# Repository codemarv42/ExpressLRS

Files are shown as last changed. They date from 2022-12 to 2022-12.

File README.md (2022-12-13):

# ExpressLRS

ExpressLRS is an open source project that enables the connection between drone and remote control in an efficient way. To support the project itself a little bit, I have developed other hardware alternatives, which are of course also open source. To support the project visit: https://github.com/ExpressLRS/ExpressLRS

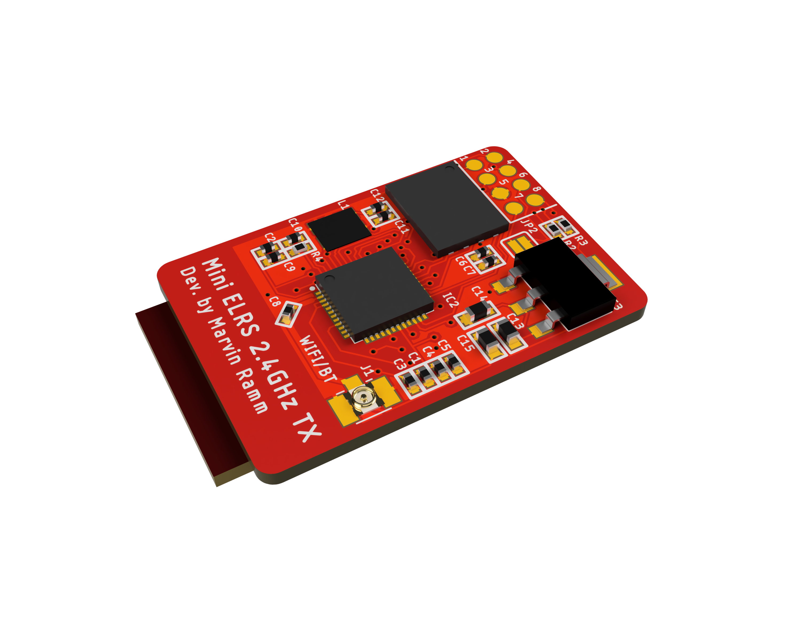
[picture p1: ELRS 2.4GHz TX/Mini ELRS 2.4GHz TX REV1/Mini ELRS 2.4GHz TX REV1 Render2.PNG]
ELRS_Render


Parameter for TX Mini REV1:

- Layer: 2
- Thickness: 1,2mm
- Minimum Copper Trace Width: 0.15mm

## Improvements

> - [ ] Pin 0 (Boot) to GND Pad for initial upload of the program

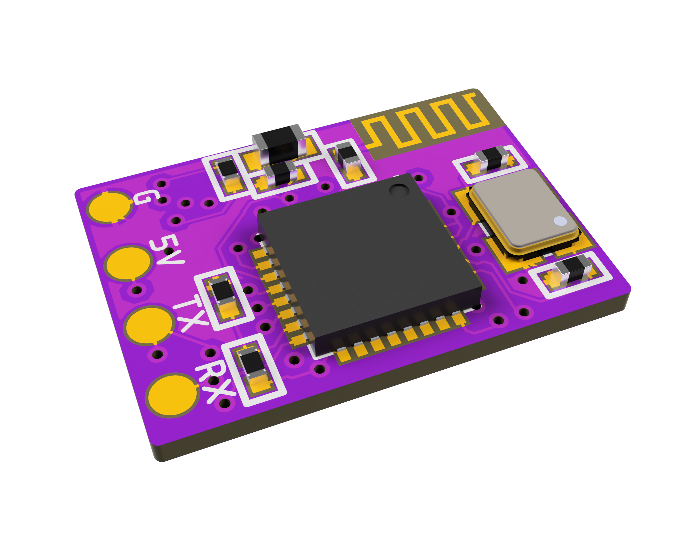
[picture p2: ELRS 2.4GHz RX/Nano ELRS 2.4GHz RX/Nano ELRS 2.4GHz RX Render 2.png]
ELRS_Render


Parameter for RX Nano REV1:

- Layer: 4
- Thickness: 1,2mm / 1mm
- Minimum Copper Trace Width: 0.09mm

ELRS_Render

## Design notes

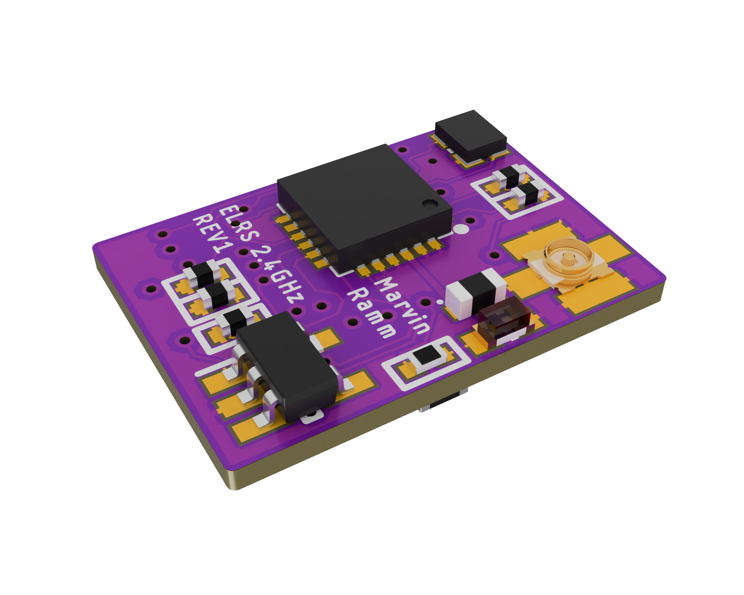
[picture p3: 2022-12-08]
ELRS 2.4GHz RX/Nano ELRS 2.4GHz RX/Nano ELRS 2.4GHz RX Render 1.png

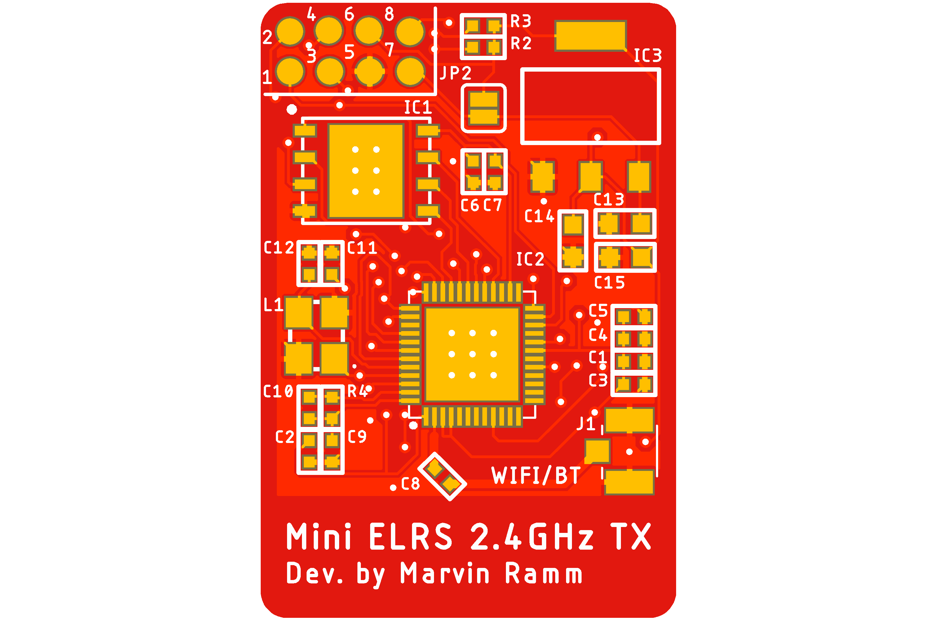
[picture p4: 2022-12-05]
ELRS 2.4GHz TX/Mini ELRS 2.4GHz TX REV1/Mini ELRS 2.4GHz TX_1.png

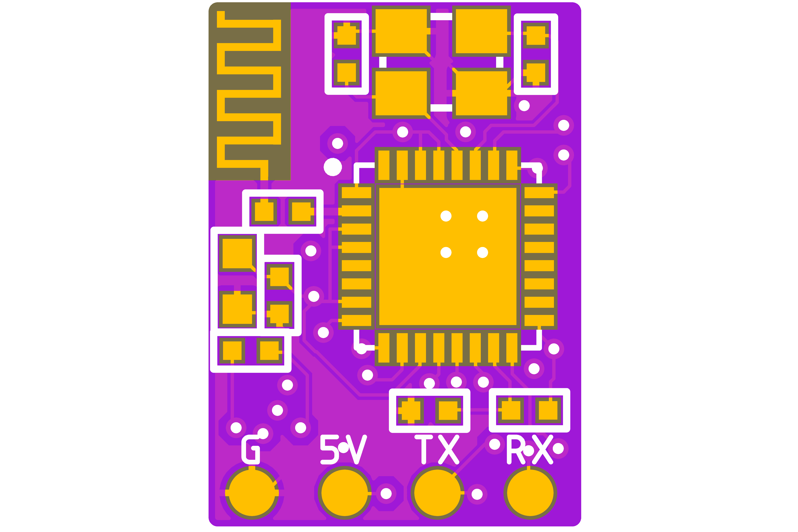
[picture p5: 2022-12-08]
ELRS 2.4GHz RX/Nano ELRS 2.4GHz RX/Nano ELRS 2.4GHz RX_3.png

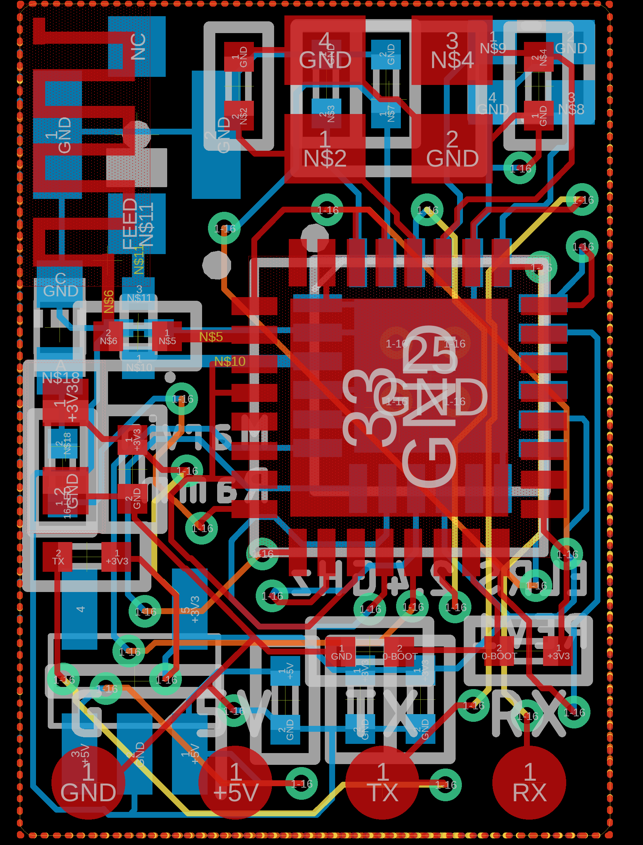
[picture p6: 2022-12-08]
ELRS 2.4GHz RX/Nano ELRS 2.4GHz RX/Nano ELRS 2.4GHz RX_1.png

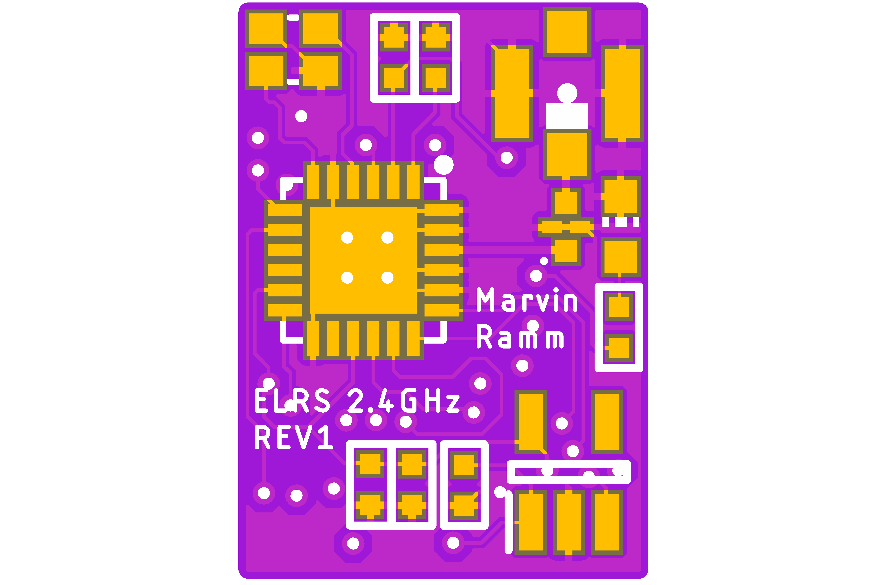
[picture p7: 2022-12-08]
ELRS 2.4GHz RX/Nano ELRS 2.4GHz RX/Nano ELRS 2.4GHz RX_2.png

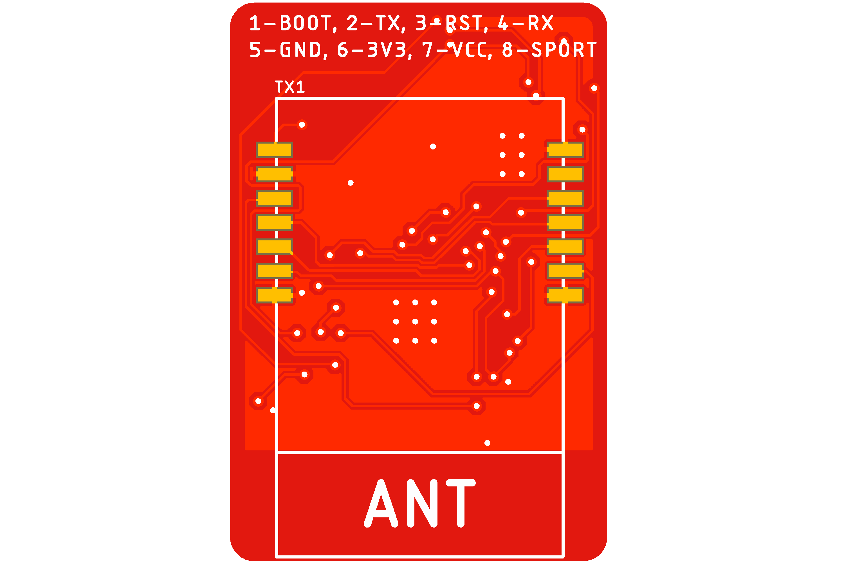
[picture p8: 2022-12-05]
ELRS 2.4GHz TX/Mini ELRS 2.4GHz TX REV1/Mini ELRS 2.4GHz TX_2.png

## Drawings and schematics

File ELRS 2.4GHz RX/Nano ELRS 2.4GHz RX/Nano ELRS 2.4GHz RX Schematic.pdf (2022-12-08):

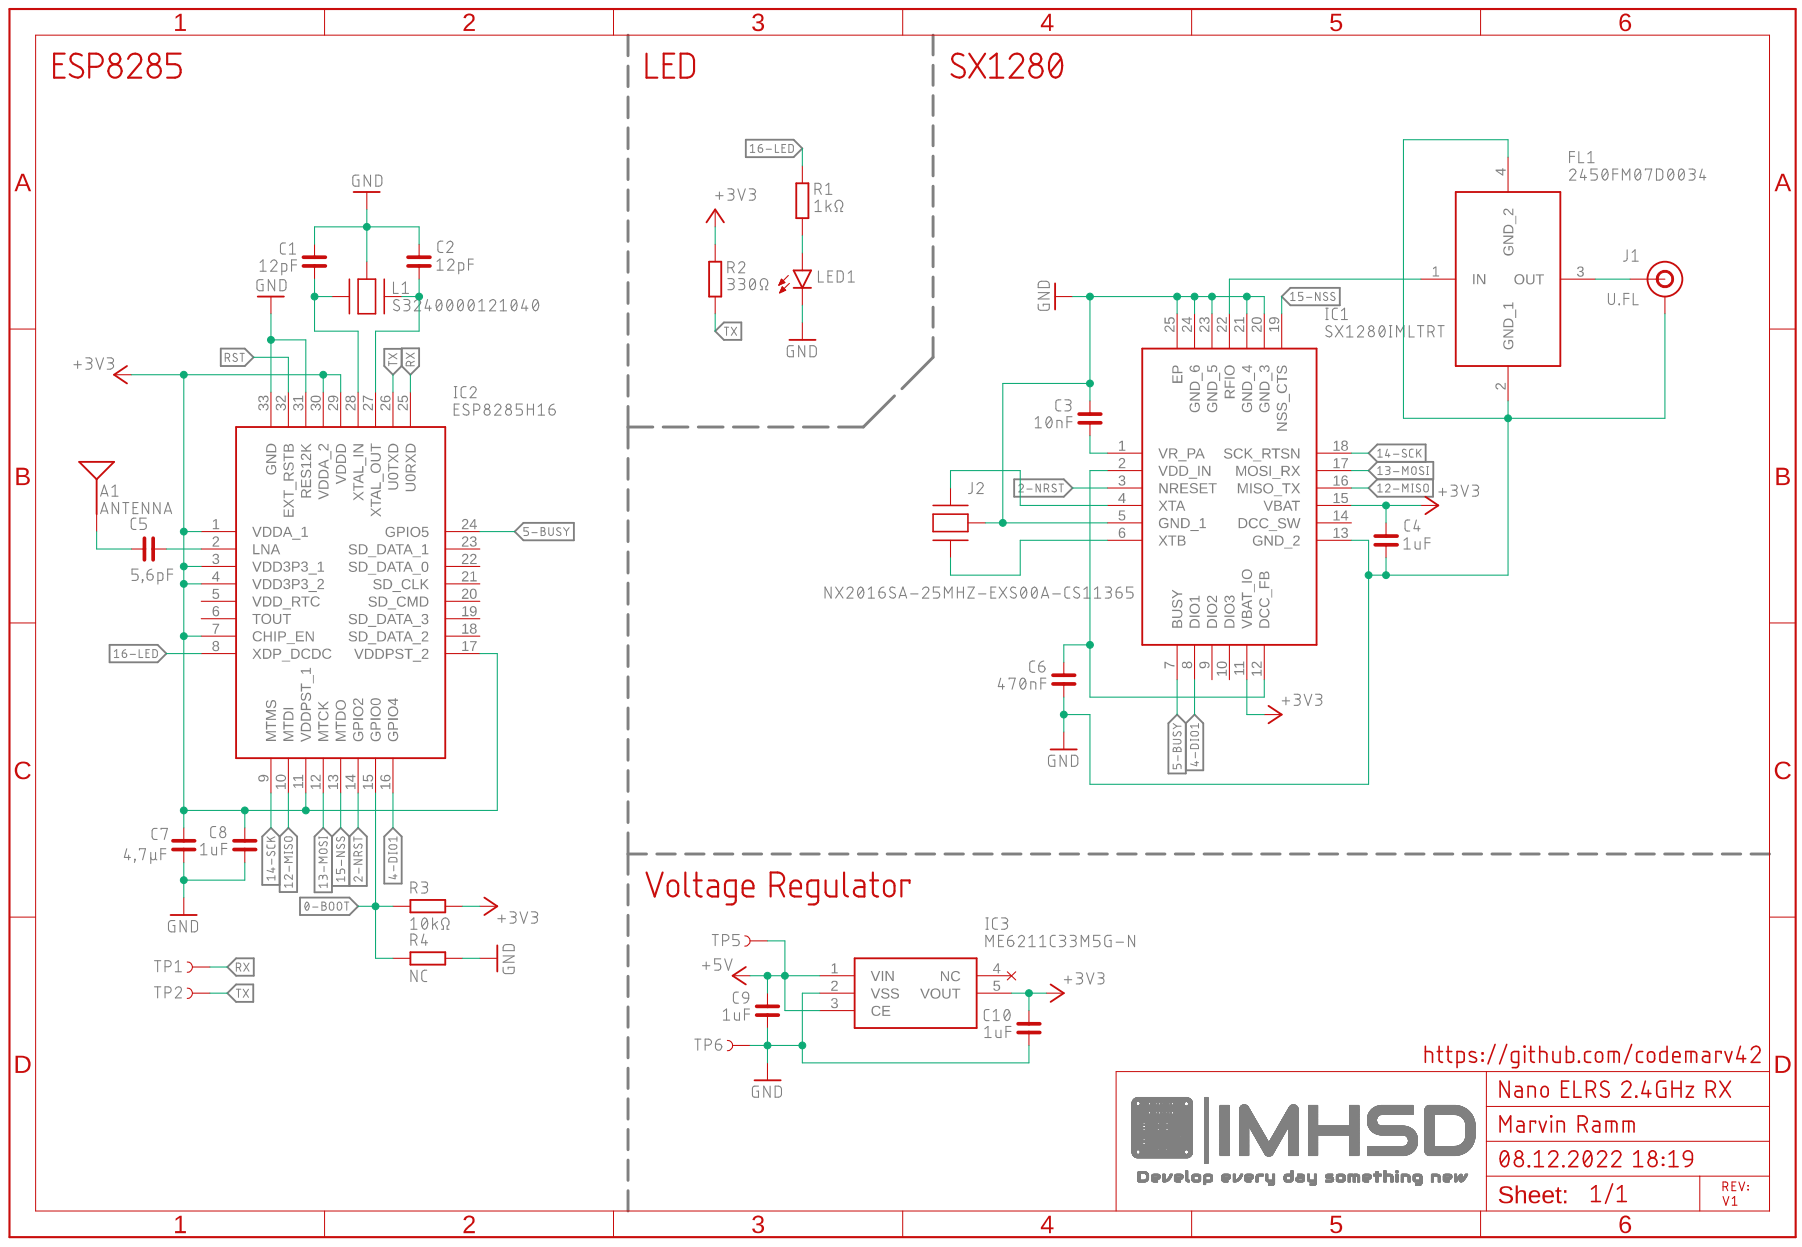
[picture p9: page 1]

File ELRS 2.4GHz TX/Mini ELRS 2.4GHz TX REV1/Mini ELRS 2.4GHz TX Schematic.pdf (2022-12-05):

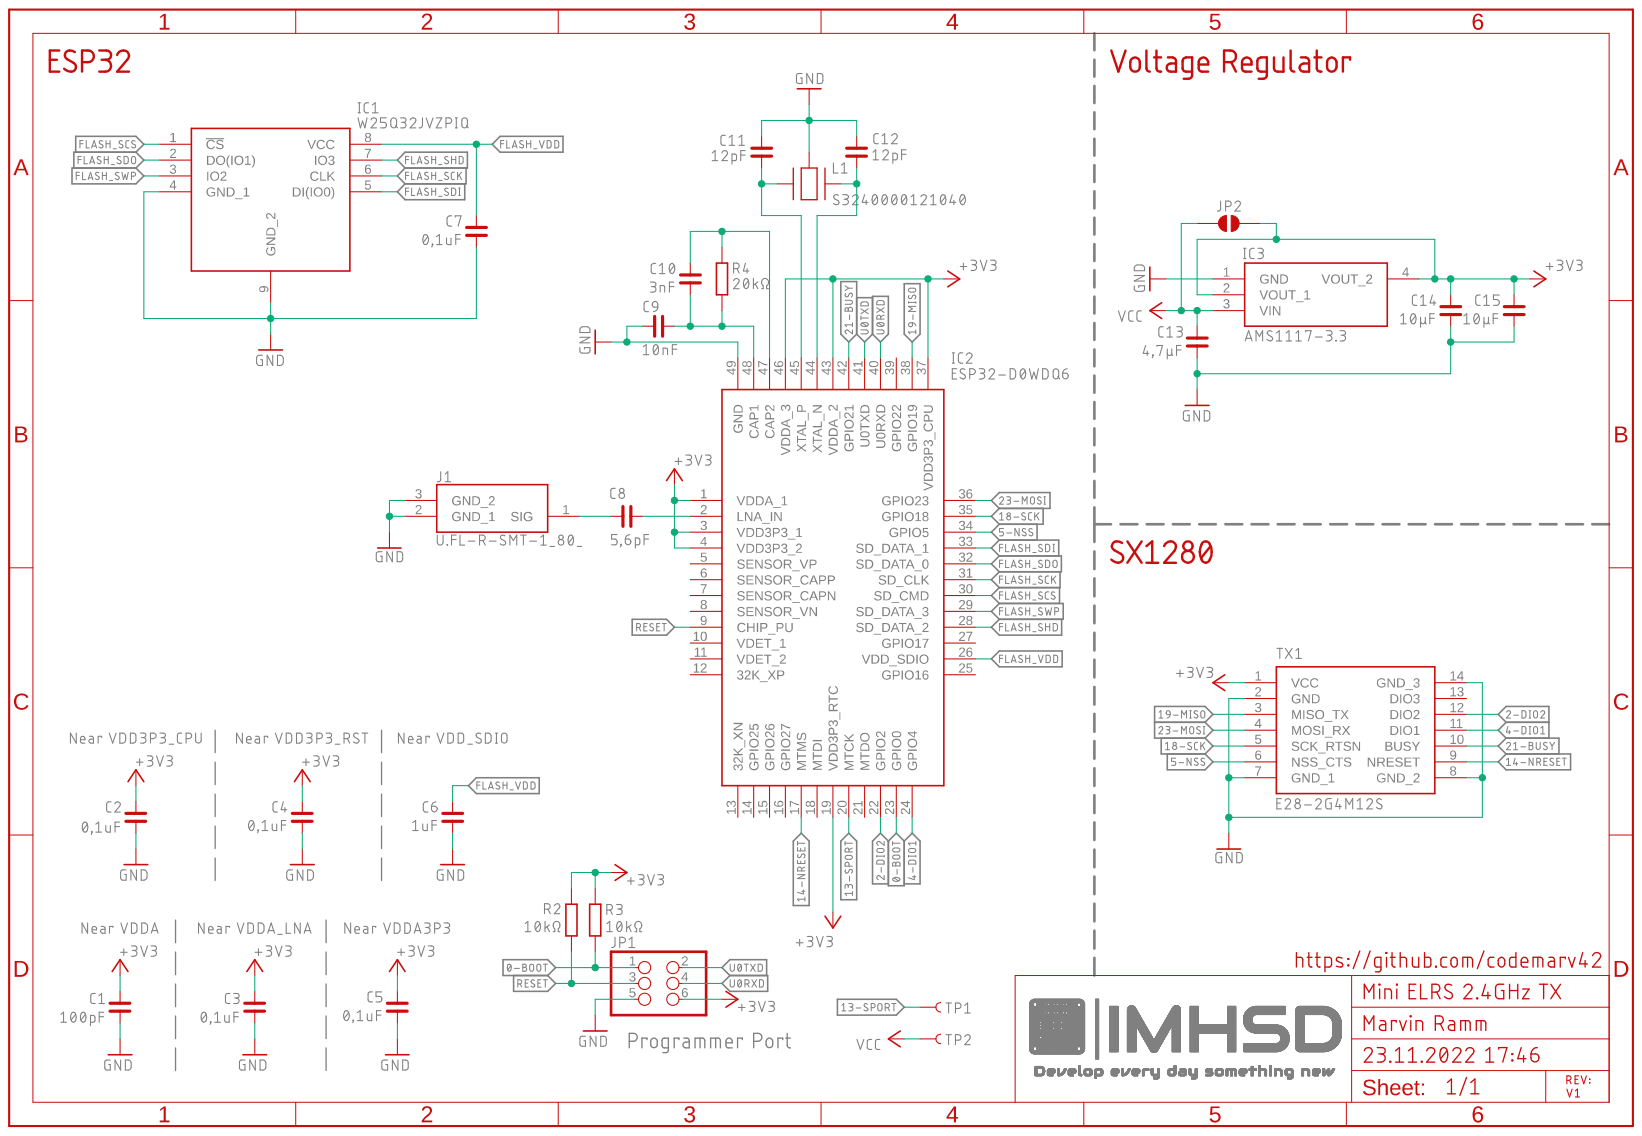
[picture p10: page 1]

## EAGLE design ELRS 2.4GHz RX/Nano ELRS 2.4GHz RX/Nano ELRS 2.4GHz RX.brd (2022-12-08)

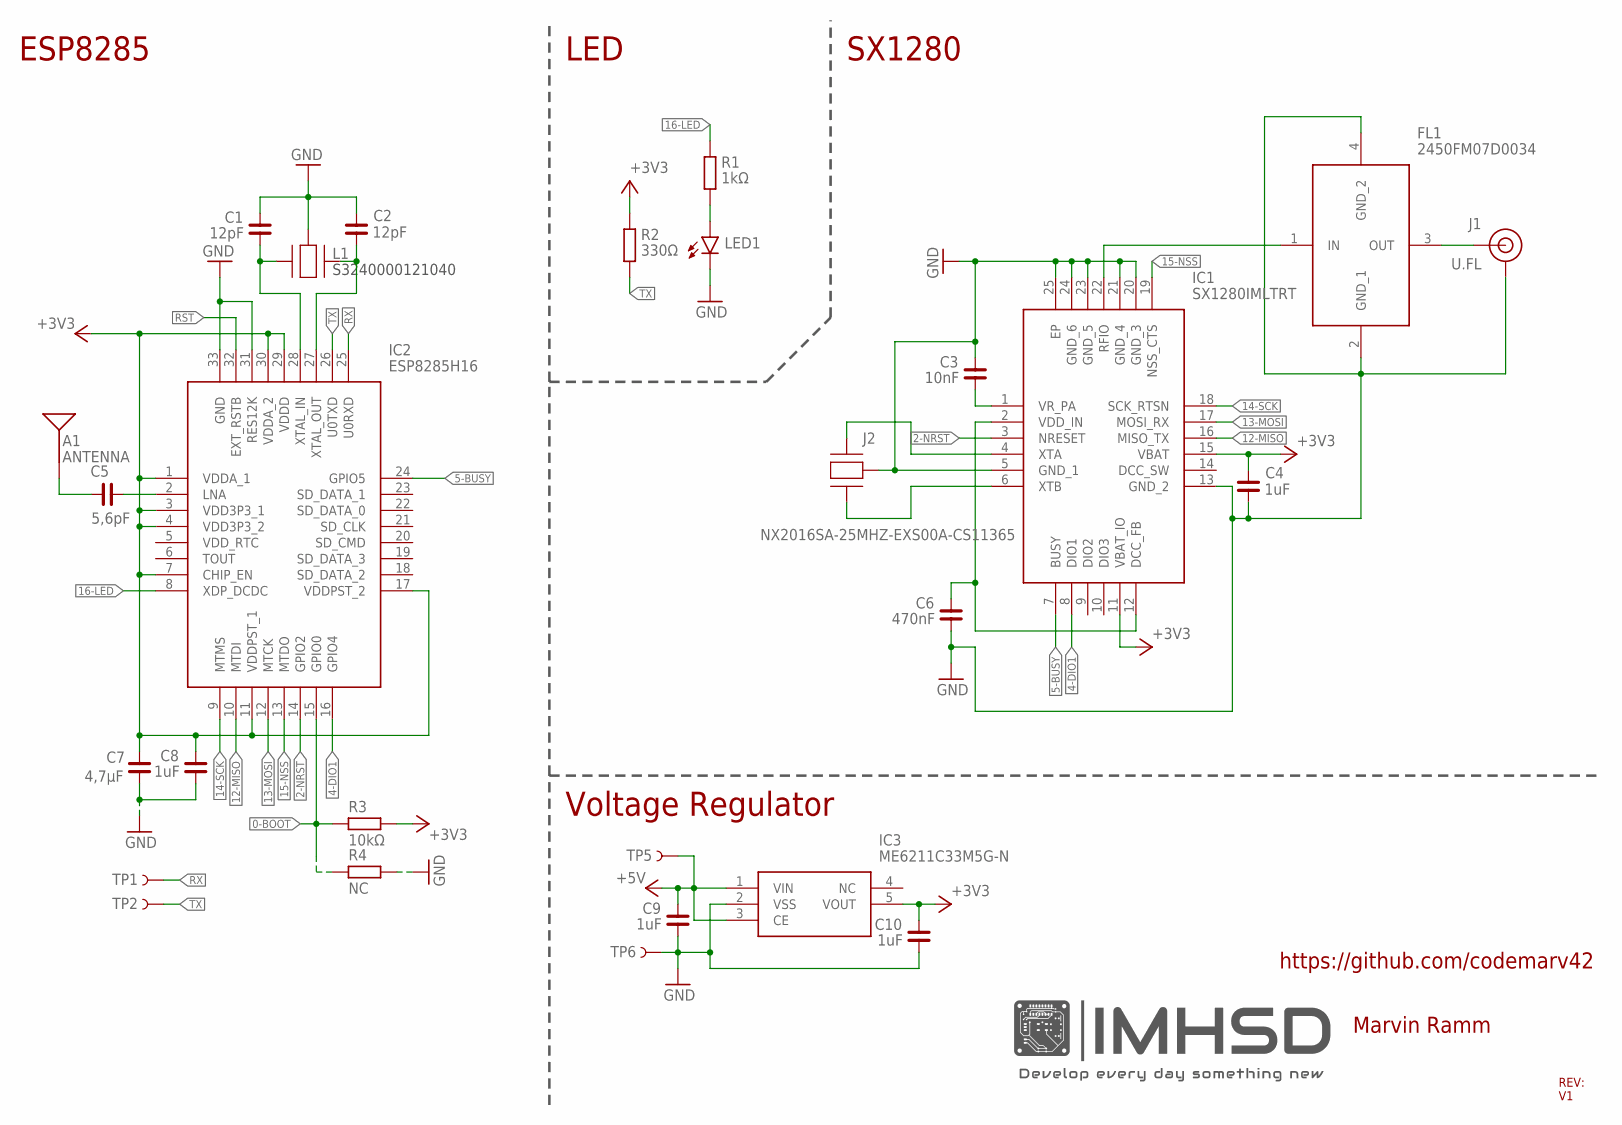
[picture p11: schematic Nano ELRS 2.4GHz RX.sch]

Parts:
A1: ANTENNA; TRACE_ANTENNA_2.4GHZ_NANO
C1, C2: 12pF; C0402
C3: 10nF; C0402
C4, C8, C9, C10: 1uF; C0402
C5: 5,6pF; C0402
C6: 470nF; C0402
C7: 4,7µF; C0603
FL1: 2450FM07D0034
IC1: SX1280IMLTRT; QFN50P400X400X100-25N
IC2: ESP8285H16; QFN50P500X500X90-33N
IC3: ME6211C33M5G-N; SOT95P270X145-5N
J1: U.FL
J2: NX2016SA-25MHZ-EXS00A-CS11365; NX2016SA25MHZEXS00ACS11365
L1: SMD-3225_4P16MHZ_20PF_10PPM_-4; SMD3225_4P16MHZ20PF10PPM4085
LED1: SZYY0603W; CHIP-LED0603
R1: 1kΩ; R0402
R2: 330Ω; R0402
R3: 10kΩ; R0402
R4: NC; R0402
TP1, TP2, TP5, TP6: TEST-POINT3X5; PAD.03X.05

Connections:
0-BOOT: IC2.15 (GPIO0), R3.2, R4.2
2-NRST: IC1.3 (NRESET), IC2.14 (GPIO2)
4-DIO1: IC1.8 (DIO1), IC2.16 (GPIO4)
5-BUSY: IC1.7 (BUSY), IC2.24 (GPIO5)
12-MISO: IC1.16 (MISO_TX), IC2.10 (MTDI)
13-MOSI: IC1.17 (MOSI_RX), IC2.12 (MTCK)
14-SCK: IC1.18 (SCK_RTSN), IC2.9 (MTMS)
15-NSS: IC1.19 (NSS_CTS), IC2.13 (MTDO)
16-LED: IC2.8 (XDP_DCDC), R1.1
+3V3: C4.1, C7.1, C8.1, C10.1, IC1.11 (VBAT_IO), IC1.15 (VBAT), IC2.1 (VDDA_1), IC2.3 (VDD3P3_1), IC2.4 (VDD3P3_2), IC2.7 (CHIP_EN), IC2.11 (VDDPST_1), IC2.17 (VDDPST_2), IC2.29 (VDDD), IC2.30 (VDDA_2), IC3.5 (VOUT), R2.1, R3.1
+5V: C9.1, IC3.1 (VIN), IC3.3 (CE), TP5.1
GND: C1.1, C2.1, C3.1, C4.2, C6.2, C7.2, C8.2, C9.2, C10.2, FL1.2 (GND_1), FL1.4 (GND_2), IC1.5 (GND_1), IC1.13 (GND_2), IC1.20 (GND_3), IC1.21 (GND_4), IC1.23 (GND_5), IC1.24 (GND_6), IC1.25 (EP), IC2.31 (RES12K), IC2.33 (GND), IC3.2 (VSS), J1.1 (GND), J1.2 (GND), J2.2 (GND_2), J2.4 (GND_2), L1.2 (GND_2), L1.4 (GND_2), LED1.C, R4.1, TP6.1
unnamed: C1.2, IC2.28 (XTAL_IN), L1.1 (CRYSTAL_1)
unnamed: C3.2, IC1.1 (VR_PA)
unnamed: C2.2, IC2.27 (XTAL_OUT), L1.3 (CRYSTAL_2)
unnamed: C5.1, IC2.2 (LNA)
unnamed: A1.ANT, C5.2
unnamed: C6.1, IC1.2 (VDD_IN), IC1.12 (DCC_FB)
unnamed: IC1.6 (XTB), J2.3 (CRYSTAL_2)
unnamed: IC1.4 (XTA), J2.1 (CRYSTAL_1)
unnamed: FL1.1 (IN), IC1.22 (RFIO)
unnamed: FL1.3 (OUT), J1.FEED (SIGNAL)
unnamed: LED1.A, R1.2
RST: IC2.32 (EXT_RSTB)
RX: IC2.25 (U0RXD), TP1.1
TX: IC2.26 (U0TXD), R2.2, TP2.1

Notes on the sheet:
S3240000121040
Marvin Ramm
ESP8285
LED
SX1280
Voltage Regulator
REV: V1
https://github.com/codemarv42

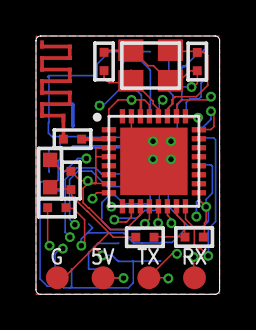
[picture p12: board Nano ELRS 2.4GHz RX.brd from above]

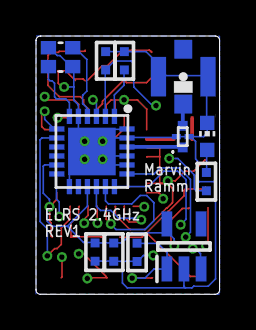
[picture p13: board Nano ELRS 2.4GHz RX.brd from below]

Board: 4 copper layers, 10.2 x 14.3 mm, 27 parts (12 on the bottom side), 25 nets.

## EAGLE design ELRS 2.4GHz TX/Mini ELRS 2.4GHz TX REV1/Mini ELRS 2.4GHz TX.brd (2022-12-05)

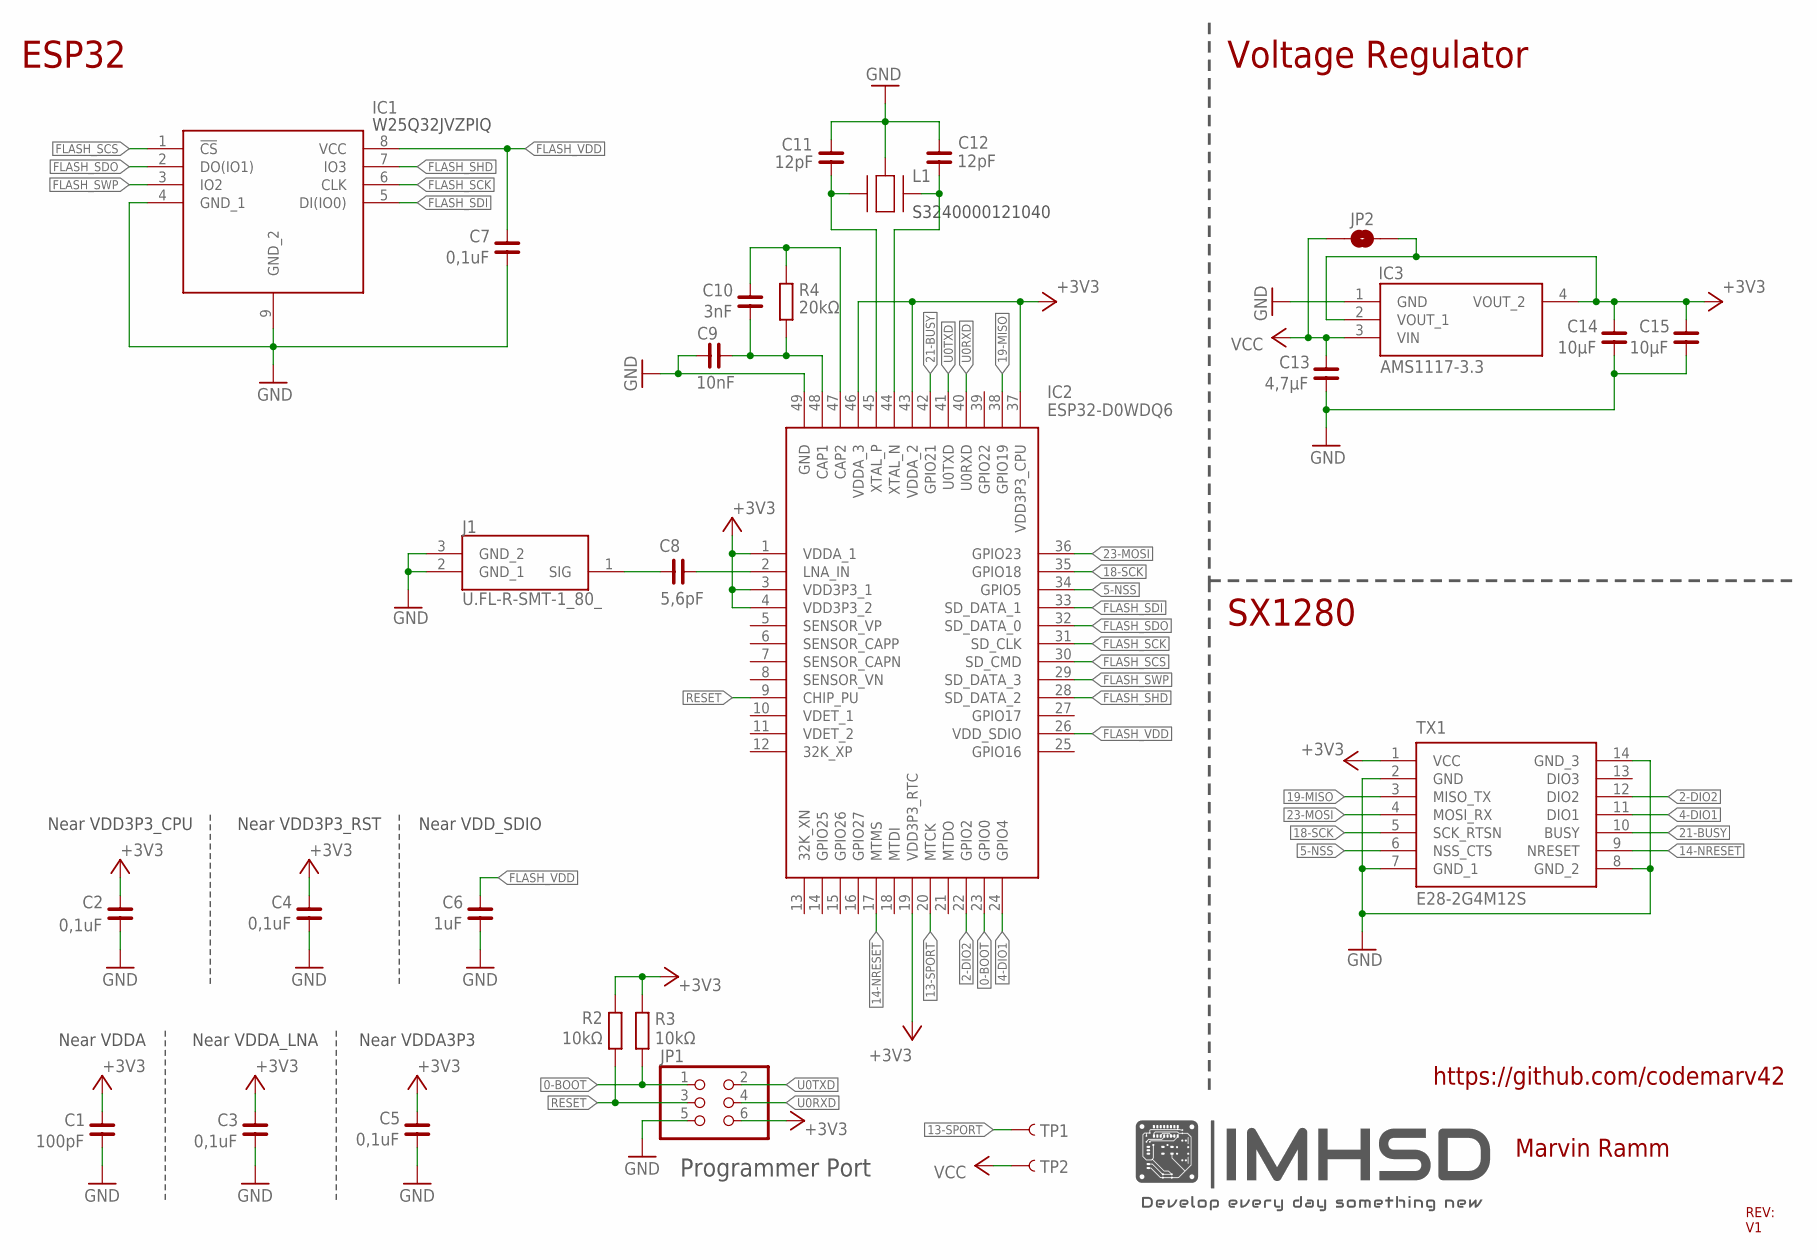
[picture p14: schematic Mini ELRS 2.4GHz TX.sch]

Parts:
C1: 100pF; C0402
C2, C3, C4, C5, C7: 0,1uF; C0402
C6: 1uF; C0402
C8: 5,6pF; C0402
C9: 10nF; C0402
C10: 3nF; C0402
C11, C12: 12pF; C0402
C13: 4,7µF; C0603
C14, C15: 10µF; C0603
IC1: W25Q128JVPIQ; SON127P800X600X80-9N
IC2: ESP32-D0WDQ6; QFN40P600X600X90-49N
IC3: AMS1117-3.3; SOT229P700X180-4N
J1: U.FL-R-SMT-1_80_; UFLRSMT180
JP1: ESP32_PRG_PORT
JP2: JUMPER-SMT_2_NO_SILK; SMT-JUMPER_2_NO_SILK
L1: SMD-3225_4P16MHZ_20PF_10PPM_-4; SMD3225_4P16MHZ20PF10PPM4085
R2, R3: 10kΩ; R0402
R4: 20kΩ; R0402
TP1, TP2: TEST-POINT3X5; PAD.03X.05
TX1: E28-2G4M12S

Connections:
0-BOOT: IC2.23 (GPIO0), JP1.1, R3.2
2-DIO2: IC2.22 (GPIO2), TX1.12 (DIO2)
4-DIO1: IC2.24 (GPIO4), TX1.11 (DIO1)
5-NSS: IC2.34 (GPIO5), TX1.6 (NSS_CTS)
13-SPORT: IC2.20 (MTCK), TP1.1
14-NRESET: IC2.17 (MTMS), TX1.9 (NRESET)
18-SCK: IC2.35 (GPIO18), TX1.5 (SCK_RTSN)
19-MISO: IC2.38 (GPIO19), TX1.3 (MISO_TX)
21-BUSY: IC2.42 (GPIO21), TX1.10 (BUSY)
23-MOSI: IC2.36 (GPIO23), TX1.4 (MOSI_RX)
+3V3: C1.2, C2.2, C3.2, C4.2, C5.2, C14.1, C15.1, IC2.1 (VDDA_1), IC2.3 (VDD3P3_1), IC2.4 (VDD3P3_2), IC2.19 (VDD3P3_RTC), IC2.37 (VDD3P3_CPU), IC2.43 (VDDA_2), IC2.46 (VDDA_3), IC3.2 (VOUT_1), IC3.4 (VOUT_2), JP1.6, JP2.2, R2.2, R3.1, TX1.1 (VCC)
FLASH_SCK: IC1.6 (CLK), IC2.31 (SD_CLK)
FLASH_SCS: IC1.1 (!CS), IC2.30 (SD_CMD)
FLASH_SDI: IC1.5 (DI(IO0)), IC2.33 (SD_DATA_1)
FLASH_SDO: IC1.2 (DO(IO1)), IC2.32 (SD_DATA_0)
FLASH_SHD: IC1.7 (IO3), IC2.28 (SD_DATA_2)
FLASH_SWP: IC1.3 (IO2), IC2.29 (SD_DATA_3)
FLASH_VDD: C6.2, C7.2, IC1.8 (VCC), IC2.26 (VDD_SDIO)
GND: C1.1, C2.1, C3.1, C4.1, C5.1, C6.1, C7.1, C9.1, C11.1, C12.1, C13.2, C14.2, C15.2, IC1.4 (GND_1), IC1.9 (GND_2), IC2.49 (GND), IC3.1 (GND), J1.2 (GND_1), J1.3 (GND_2), JP1.5, L1.2 (GND_2), L1.4 (GND_2), TX1.2 (GND), TX1.7 (GND_1), TX1.8 (GND_2), TX1.14 (GND_3)
unnamed: C8.2, J1.1 (SIG)
unnamed: C8.1, IC2.2 (LNA_IN)
unnamed: C9.2, C10.1, IC2.48 (CAP1), R4.2
unnamed: C10.2, IC2.47 (CAP2), R4.1
unnamed: C12.2, IC2.44 (XTAL_N), L1.3 (CRYSTAL_2)
unnamed: C11.2, IC2.45 (XTAL_P), L1.1 (CRYSTAL_1)
RESET: IC2.9 (CHIP_PU), JP1.3, R2.1
U0RXD: IC2.40 (U0RXD), JP1.4
U0TXD: IC2.41 (U0TXD), JP1.2
VCC: C13.1, IC3.3 (VIN), JP2.1, TP2.1

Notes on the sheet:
S3240000121040
Near VDDA
Near VDDA_LNA
Near VDDA3P3
Near VDD3P3_CPU
Near VDD3P3_RST
Near VDD_SDIO
Programmer Port
W25Q32JVZPIQ
Marvin Ramm
REV: V1
https://github.com/codemarv42
ESP32
Voltage Regulator
SX1280

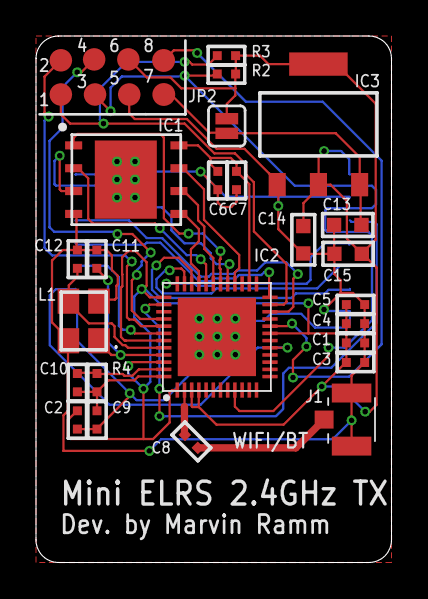
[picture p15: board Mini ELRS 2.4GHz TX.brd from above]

Board: 2 copper layers, 19.8 x 29.2 mm, 28 parts (1 on the bottom side), 29 nets.

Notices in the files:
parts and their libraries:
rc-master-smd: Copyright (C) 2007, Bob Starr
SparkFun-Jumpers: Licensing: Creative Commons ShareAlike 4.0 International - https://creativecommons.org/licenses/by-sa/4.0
